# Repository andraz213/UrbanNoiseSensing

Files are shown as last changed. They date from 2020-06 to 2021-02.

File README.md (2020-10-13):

# Sensor network for urban noise sensing with IoT
Bachelors thesis

Currently on: http://urbannoisesensing.biolab.si/

## Overview

Noise is a huge health and quality of life hazard. It is most prominent in big cities, especially in city centers. 
There are ways to manage the amount and type of noise being present in these environments.
Material and architectural choices can have a tremendous impact on noise. 
But good decisions can only be made with an appropriate amount of information. A lot of times, there's not enough data to show that something needs to be done, let alone what kind of impact a specific choice will have on overall noise.

This system will help city planners and architects discover where most changes are needed and what kind of impact their past choices have on overall noise levels. 
There are a lot of systems that measure noise on a macro level. There are sensors placed on each street and research is done on a city level. 
This system will take a different approach. There will be multiple sensors on each street, meaning that research will be done on a micro-level. We want to figure out how very specific materials and structures impact noise levels in the real world. That is possible by deploying a lot of affordable sensors and using the latest machine learning methods that take into account spatial and temporal dimensions. 

This is a highly specialized system with tightly defined goals and specifications.
Here are most of these goals:

- affordable sensor nodes
- synchronized data sampling 
- FFT spectral analysis and noise volume data
- battery-powered and autonomous operation for at least a few days at a time
- wireless 
- REST API interface for data collection and querying
- support for geospatial data
- backend deployment on a local server
- easy and intuitive sensor deployment

## Basic structure

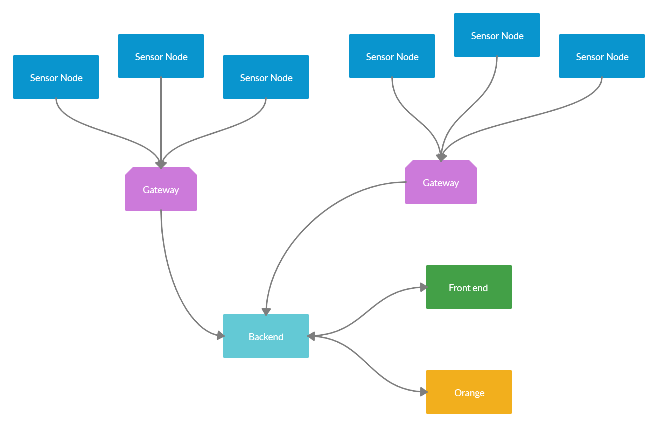
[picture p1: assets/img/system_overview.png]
System Overview


The heart of this system is a backend that is deployed on a local server. It is using Node.js, Express, and MongoDB to expose the appropriate endpoints, do basic data processing and data storage.

Gateways are needed to overlay the data from sensors to the backend. Direct wifi connection is way too inefficient for this application, that's why a special low power, low overhead wireless protocol will be used to transfer captured data from the sensors to the gateway and the to the backend. 

Sensors will consist of a low powered MCU that supports wifi-like protocols used in this system and offer enough processing power to do the FFT spectral analysis as close to the source of data to cut down on bandwidth power cost, a low-cost microphone with a flat frequency response curve and tight manufacturer tolerances, a battery to power the sensor node and some other miscellaneous components. 

The front end will enable administrators to check sensor staus and create sensor deployments. Deployments are a way of provisioning sensors on a project. 

The end-users and researchers will be able to access the data through REST API endpoints and use it in Orange or other machine learning or research tool. 

# System usage

The general concept is to create deployments. Since batteries in the sensors will only last a few days, the act of sensing can be considered as a sort of a deployment or a study.
The system will be used to study one street or one feature at a time, so these deployments can be considered as studies of individual microelements that affect the noise. 

The general overview is then: 
1. Choose the sensors
2. Mount the sensors and get the data 
3. Access the data when doing the analysis

## First step

At first, there will be no registered sensors or gateways. The first step is to turn them all on. Gateways in their normal and only mode and sensors in their administration mode.
When all of them connect to the designated wifi hotspot, they will connect to the backend and get their unique ids, check for updates and send their telemetry data. 
The first step is the easiest and will allow for all the sensors and gateways to be programmed in the same way with the same firmware (sensors and gateways will have separate firmware).

## Create a deployment

Deployment is a way to manage data and sensors. 
It will help structure and navigate the data and it will make the sensor management a lot easier. 

Here are the steps to creating a deployment:
1. Set the deployment name and description
2. Select sensors that will be used in this deployment
3. Place the sensors on a map to set their location
4. Select which gateways will be used 
5. Place gateways on the map and type in wifi credentials
6. Save changes

When the changes are saved, the new deployment and appropriate new data buckets will be created. Deployments will allow a quick overview of the latest data and sensor status after sensors are deployed on location.

## Before sensing

All of the sensors must be turned on in the administration mode to collect all the necessary setup data. 
After the data has been transferred, the sensors can be turned off until they're mounted in their spots. 

## Afer sensing

After the sensing is over, the deployment can be marked as finished. All the sensors and gateways will be released and their location and current deployment will be set to null to indicate that they are ready to be deployed again. 

The data is available while the deployment is active and after the sensing is over.

# Sensor node

## Firmware

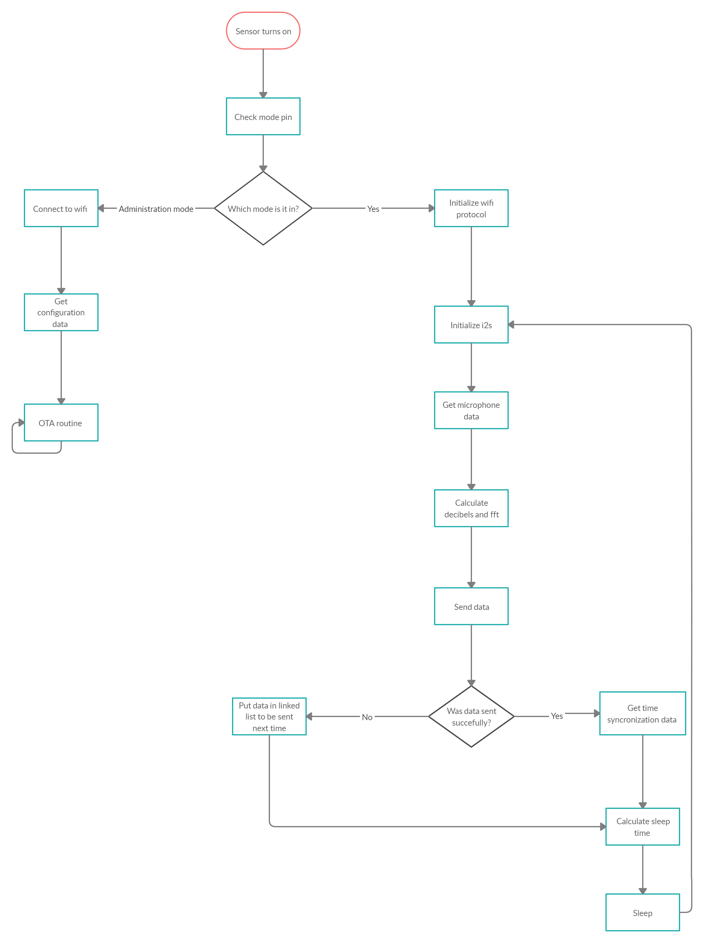
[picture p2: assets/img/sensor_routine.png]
Sensor routine


A general overview of how the firmware on the sensor node will operate.

### Setting up

When the sensor node is first programmed, it should have generic settings.
The only thing set is what wifi it should connect to.
What's next?

Firstly, it needs a unique classifier or id, so the server knows which node sent the data. Luckily, every esp comes with a unique mac address. It will be used to acquire a unique identifier from the backend. 

Then it needs to send telemetry data like firmware version, battery voltage, mac address,...

It should go something like this:

1. Connect to wifi
2. Send a "do you know me" message to the server with mac address
3. Wait for a response
4. If ok, send telemetry data

### Provisioning

Once the sensor node is set up, it needs to get some more information before it can start measuring and sending the data.

It needs:

- Gateway mac address. To send data with ESPNOW protocol, the device needs to know the MAC address of the receiver
- Sampling rate. While one measurement per second might be fine, it needs to be modifiable to make it more robust
- Frequency range. While most noise we're interested in is below 1kHz, this needs to be modifiable as well

Most provisioning work is done on the backend, so this is probably all that is needed here.

This provisioning data is sent when the sensor node is turned on in the administration mode and connected to the wifi.

### Sensing

The other mode of operation is sensing.
Before it can start collecting the data and sending it to the gateways, it needs setup data. This data is sent after the deployment is created in the frontend and the sensor node has been turned on in the administration mode.

Sensing mode is a continuous cycle of four activities:
1. Getting the readings
2. Processing the data 
3. Sending the data 
4. Sleeping

Another activity is time synchronization. The sensor asks gateway what time in milliseconds it is, so it can put a time stamp on the sensed data when sending it and to start collecting sound samples at the same time as all the other sensors. 

#### Getting the readings

The sensor of choice here is a MEMS microphone (INMP441). It communicates through the i2s protocol. This protocol is a specialized protocol for transferring sound data.
Before actually getting the data, the i2s driver needs to be initialized. 
Once the driver has been initialized, the DMA transfers data from the i2s peripheral device to the designated buffer. 
After the buffer is full, it needs to be read. 

The whole operation should go like this:
1. Initialize 12s driver
2. Wait 100ms
3. Read the data from the buffer

#### Processing the data 

Once the data has been collected from the i2s buffer, it needs to get processed. 
Three main processing tasks need to be done in this stage. 

1. Calculate the fft
2. Calculate the decibels
3. Lower the FFT resolution to 10-20 frequency ranges

#### Sending the data 

After the data has been processed, it needs to be sent. 

the data will be packaged into a struct and sent.

```
struct data_transfer_struct
{    
    float decibels;
    long time;
    int fft_spectrum [10-20];
};

``` 

When the data is sent, an automatic acknowledgment is done. If the data was successfully sent, the outgoing packet is discarded and the device can sleep.
If data transmission failed, the data must be saved and sent at a later time. It will be done in this stage when the next data transfer is successful.  

#### Sleeping

After sending is done, the MCU needs to go to sleep to conserve power and extend battery life. 
ESP32 supports different types of sleep:
- modem sleep
- light sleep
- deep sleep
- hibernation

Each has its advantages. I chose light sleep for this application. It does have much higher consumption than deep sleep, but it wakes up faster. 
Waking up from deep sleep takes about 250ms. That is a significant portion of the sensing mode operating cycle. 
Light sleep retains all the data in ram and execution can be resumed right after the light sleep function call. 

## Hardware

### MCU

I chose ESP32 MCU for this project.
It has excellent library support, wifi range is quite large, it has i2s for the microphone, it has great low power capabilities, it is powerful enough for all fft calculations, price.

The exact specific model is WROOM 32U because it has an external antenna connector. PCB antennas tend to be spotty and have a lot of signal shape peculiarities that are less than ideal in this kind of application.
The bad thing about this is that all of the development boards have a very inefficient LDO AMS1117. It is a voltage regulator with a high quiescent current. It consumes 5mA of power at all times. That is unacceptable. I will have to replace those with a more efficient model like MCP1825S. It has a quiescent current of only 220uA, which is far from the lowest, but it's good enough for this application.

### Antenna

This is yet to be determined. I have a few antennas ordered off of aliexpress, but I have to test them first. A lot of antennas are poorly made or just plain wrong.

### Battery

Sensors will be powered by one or two 18650 batteries. They seem to be a good choice because of their low price and availability. I'm not sure whether ordering them off aliexpress is a good idea tho.
Battery management will be done with a cheap tp4056 board. It has a charging circuit, overcharge protection, overcurrent protection, and over-discharge protection built into a small footprint.
I will use battery holders since I'm not comfortable with welding wires directly to the batteries.

### Microphone

A MEMS i2s microphone was chosen. MEMS microphones generally have very tight manufacturing tolerances and a flat frequency response curve. They are weather-resistant and can work under extreme temperature conditions.

INMP441 was chosen for an affordable price, great performance, compatibility with esp32, and because it comes on an easy to use a breakout board.

Decibel meter project: https://github.com/ikostoski/esp32-i2s-slm

I still have to source an appropriate wind protector.

### Enclosure

It will most probably be a weatherproof ABS plastic container. 
Haven't found one yet.

# Gateway

Gateway will be used to receive data from the sensors and send it to the backend. 
If I was only using ESPNOW protocol, I could only use one ESP32 in the gateway, but because I'm also using 802.11LR protocol, I will need two of them. 
The first one will handle all the data coming from the sensors and the time synchronization. The second one will take the received data, package it into JSON format, and send it to the backend.

These two ESP32s will communicate over the UART connection with a special PJON protocol. https://www.pjon.org/ThroughSerial.php

# Backend

## Database 

MongoDB will be used.
Measurements will be collected in size based buckets. 

### Size based buckets

MongoDB is not equipped to handle time-series data very well. Many other databases would be much more appropriate from a performance standpoint.
This can be mitigated with a few clever tricks. 

The main one is to store data in size based buckets. A naive approach to storing data is to just save each measurement as a single document. This is easier to implement, but the problem arises when the number of sensor nodes increases. If data collection is done every second and there are 20 nodes, it would mean that there would be more than 1.7 million new documents created every single day. Querry performance even after one month would be less than ideal. 
That's why I will use buckets to store data. Most of the data stored in a single document is be the same as a lot of other documents, so they can be merged. Sensor node does not move, its id does not change and the deployment id doesn't change as well, so I need to store all that data once and then just append measurement data to an array. Each element of that array will have the measurement data and a timestamp. If bucket size is set to 1000, there will be only about 1700 new documents created every day, or about 87 per single sensor.   

## Data structure 

MongoDB is a document-driven database. 

Models used:

- Deployment 
- Data
- Gateway
- Sensor 

### Deployment

This model will be used to store all the relevant deployment-related data and configuration.

```
id: number
name: string
description: string
sensors: [sensor.id, coordinates]
gateways: [gateway.id, coordinates]
start: time
finish: time
measurement_num: number
tags: [string]
```
 
- id is a random unique number generated by MongoDB used as an identifier.
- name is a string that is used to recognize deployments easier.
- description is a deployment description with more details about this deployment. 
- sensors is an array that will save which sensors are deployed where.
- gateways is an array of gateway ids and location data
- start is the time of the first measurement
- finish is the time of the last measurement
- measurement_num is the number of measurements
- tags is an array of tags that will help to search 

### Sensor

This model will hold crucial sensor data. 

```
id: number
name: string
mac: [number] (maybe string)
deployments: [deployment.id]
current_deployment: deployment.id
current_location: [number]
last_telemetry: time
last_data: data.id
firmware_version: string
battery_voltage: number
```

- id will hold the unique identifier
- name is a randomly generated name that will make identification easier to humans
- mas is a mac address of this sensor
- deployments is an array of all past deployments
- current_deployment is the id of the current deployment
- current_location is the current location of the sensor
- last_telemitry is the time and date of the last received telemetry
- last_data is the id of the last data bucket that is currently getting filled up
- firmware_version is the version of currently installed firmware
- battery_voltage is last measured voltage

### Gateway

Will hold all the relevant data for the gateway.

```
id: number
name: string
mac: [number] (maybe string)
deployments: [deployment.id]
current_deployment: deployment.id
wifi_credentials: [string]
current_location: [number]
last_telemetry: time
firmware_version: string
```

- id will hold the unique identifier
- name is a randomly generated name that will make identification easier to humans
- mas is a mac address of this sensor
- deployments is an array of all past deployments
- current_deployment is the id of the current deployment
- wifi_credentials is to let the gateway know which wifi it should connect to when it is deployed 
- current_location is the current location of the sensor
- last_telemitry is the time and date of the last received telemetry
- firmware_version is the version of currently installed firmware

### Data

Is a bucket structure that will hold incoming data.

```
id: number
sensor: sensor.id
deployment: deployment.id
location: [number]
size: number
first: time
last: time
data: [data structure]
```

- id is a unique identifier
- sensor is which sensor is this data from
- deployment is which deployment does this data belong to
- location is where was this location captured
- size is the number of measurements data currently in this bucket
- first is the time of the first measurement in this bucket
- last is the time of the last measurement in this bucket 
- data is an array of measurements, each measurement will have its timestamp and the data 

I might implement this as a linked list. Just to make it easier to get the data in the right order. I'm not sure whether this is a good idea yet, but it might be useful. 

## Exposed data 

Data about measurements, sensors, and gateways will be available through REST API for analysis in Orange or other platforms.

I don't know what exact data will be needed, but here are my guesses.

### GET /api/deployment

It will return an array of basic deployment data from all deployments.

```
[
id: number
name: string
number_of_sensors: number
start: time
finish: time
number_of_measurements: number
]
```

### GET /api/deployment/{deployment.id}

It will return a single document with the same data as the deployment model.

```
id: number
name: string
description: string
sensors: [sensor.id, coordinates]
gateways: [gateway.id, coordinates]
start: time
finish: time
measurement_num: number
tags: [string]
```

### GET /api/sensor

It will return an array of all sensors with basic data.

```
[
id: number
name: string
current_deployment: deployment.id
battery_voltage: number
]
```

### GET /api/sensor/{sensor.id}

It will return all data that is in the sensor model 

```
id: number
name: string
mac: [number] (maybe string)
deployments: [deployment.id]
current_deployment: deployment.id
current_location: [number]
last_telemetry: time
last_data: data.id
firmware_version: string
battery_voltage: number
```

### GET /api/gateway

It will return an array of all gateways with basic data.

```
[
id: number
name: string
current_deployment: deployment.id
]
```

### GET /api/gateway/{gateway.id}

It will return all data that is in the gateway model 

```
id: number
name: string
mac: [number] (maybe string)
deployments: [deployment.id]
current_deployment: deployment.id
current_location: [number]
last_telemetry: time
firmware_version: string
```

### Data 

Querying data will be the major part of backend work. 

It's more or less a guessing game at this point, but here are my predictions as to which endpoints will be needed.

#### GET /api/data/deployment/{deployment.id}

It will return all the data from a single deployment. 

```
[
sensor: sensor.id
deployment: deployment.id
location: [number]
size: number
first: time
last: time
data: [data structure]
]

```

The structure will be similar to the one seen in the data model, but all the data from a single sensor will be in a single array.

#### GET /api/data/deployment/{deployment.id}/{last_n}

It will return the last n measurements.
Note that one measurement is actually one measurement per sensor, so this method will return last n measurements for each sensor.

```
[
sensor: sensor.id
deployment: deployment.id
location: [number]
size: number
first: time
last: time
data: [data structure]
]

```

#### POST /api/data/deployment/{deployment.id}/

The request body will contain additional query data. 

Possible additional parameters:
- return measurements before this time
- return measurements after this time
- return measurements from these sensors 
- return last n measurements
- more?? @@@

## Exposed sensor and gateway endpoints

More REST API endpoints will be needed to set up the sensors and gateways and to make them work.

### POST /api/sensor/

This is where it all starts for the sensor. When the sensor is first turned on in administration mode, it will send its mac address to the server to register as a sensor node.
The server will return its generated id and name.
If the sensor is deployed, the server will also return basic configuration data like the nearest gateway mac address. 

### POST /api/sensor/telemitry/{sensor.id}

After the first call, the sensor will enter a loop, where it will report it's battery voltage and firmware version every few minutes. The server will return data about the latest firmware version. If there is a new firmware version, the sensor will enter the OTA mode where it waits for the update to start.
If it is already running the latest firmware, it will only report its voltage every few minutes. It is useful to have a remote battery charging status. 

### POST /api/sensor/data/

This is a gateway endpoint. It will send an array of measurements. When testing, I noticed that each POST request took almost half a second. That is way too much if the sensors are sending data every second and there are 10 sensors, it would take 5 seconds to send data each second. So gateway will send an array of measurements that it has collected since the last time it sent data. Each measurement will have a sensor id and the actual data. The server will then insert the data into appropriate buckets.

### POST /api/gateway/

Similar to the sensor, this is where all gateways will start. The gateway will send its mac address to the server to either get its id and deployment data or register for the first time as a gateway. 
The server will respond with appropriate gateway data.

### POST /api/gateway/telemitry/{sensor.id}

An endpoint for gateways to send their telemetry data. 

# Izbira tehnologije

## Povezava senzorjev z internetom

Zahteve:
- obratovanje na baterije
- dovolj velik obseg vsaj 200m obseg (@@@ a je to res?)
- hitrost prenosa podatkov, vsak senzor generira cca. 200B/s ... 20 senzorjev generira 4KB/s

### LoRa

Na prvi pogled izgleda obetavno z zelo majhno porabo energije in velikim dometom (2-3km).
Problem je izredno počasna povezava. V najboljših razmerah je 20kbps. Naše zahteve so 4KB/s * 8 = 32kbps.
LoRa po mojem mnenju potem odpade zaradi prepočasnega prenosa podatov

### NRF24l01+

Je dokaj preprosta tehnologija, ki omogoča hitro povezavo na srednje dolge razdalje, je dovolj hitro, ampak ima dve pomankljivsoti.
Tehnologija dovoljuje največ 6 povezav na vsak modul. Za potrebe naše uprabe bi načeloma lahko uporabili mrežo takih točk, ampak to poveča kompleksnost projekta in oteži postavljanje senzorjev

### 802.11LR

Espressif, proizvajalec čipa ESP32 je implementiral poseben protokol, ki je kkompatibilen z 802.11, ampak ga navadne wifi točke ne zaznajo. Omogočal naj bi daljši domet kot navaden wifi.
To je doseženo z zmanjševanjem hitrosti pod 1Mbps, kar bi bilo za ta projekt še zmeraj dovolj. Problem tega je, da je še zmeraj prisoten overhead od wifija, kar močno poveča količino porabljene energije. Tu bi moral podatke pošiljati recimo enkrat na minuto, kar ne bi bilo več real time, ampak zaradi porabe energije ne bi šlo drugače. Tu bi tudi potreboval gateway, ki bi sporočila preko tea protokola sprejela in potem poslala na internet.

### Kreativne alternative

#### SD kartice

V modulu je RTC, ki se ga enkrat nastavi in potem zansljivo drži pravilen čas in podatki se beležijo na SD kartico, s katere se podatki poberejo ob polnenju baterij.

#### GSM moduli

Naprava komunicira preko GSM vmesnika in tako pošilja podatke na strežnik. Tu je še dodatni strošek recimo 7€ na mesec na senzor. Plus GSM modul, ki stane 5€. Ne vem kako je s porabo energije, ampak če bi podatke pošiljal pv paketih, bi lahko to minimiziral.

### Testiranje tehnologij

Ker imam doma nekaj nrf24l01+ modulov z vgrajenim ojačevalnikom moči, sem testiral domet in zanesljivost.
Prav ta ko imam doma nekaj ESP32 modulov s katerimi sem testiral domet 802.11LR protokola.

Zaenkrat se je 802.11LR izkazal za boljšega. Domet je vsaj še enkrat daljši.

Oba modula sem imel na okenjski polici svoje sobe. Hodil sem po kraju in opazoval koliko sporočil je prišlo do sprejemnika.

nrf24 z vgrajenim ojačevalnikom signala in cca 3dBi anteno:
- Takoj ko je bila med mano in oddajnikom hiša, je sperjemnik izgubil signal
- Line of sight doseg je bil približno 80m

802.11LR ESP32 z vgrajeno anteno na tiskanem vezju s cca 2dBi:
- Je deloval tudi na drugem koncu hiše in do neke mere celo ko je bila med mano in oddajnikom sosedova hiša
- Line of sight doseg je bil približno 160m

Test sem z 802.11LR ponovil doma v hiši. Oddajnik sem postavil na podstrešju na skrajno vzhodni strani.
- V istem nadstropju je signal brezhiben
- Eno nadstropje nižje je signal brezhiben in se sprejemnik poveže v vseh delih nadstropja razen v najbolj zahodnih delih hiše.
- V spodnjem nadstropju se sprejemnik poveže in brezhibno sprejema signal povsod razen v 1/3 najbolj zahodnega dela hiše

Ob ponovitvi testa 802.11LR z oddajnikom na podstrešju, sem izmeril line of sight domet 200m, ampak le če je bil modul obrnjen v pravo smer. Zunanja antena bi pri tem precej pomagala.

Testirano je bilo na razvojnih ploščah, ki imajo na tiskanem vezju vgrajene antene. Te antene najverjetneje niso najboljše, kar poemni, da bi z boljšimi antenami dosegli še boljše rezultate.

### Trenutnne možnosti

#### LoRa

Zaenkkrat odpade, razen če zmanjšamo količino poslanih podatkov pod 15kbps.

#### NRF24

Pogojno bi se dalo, če bi strateškko postavili senzorje in zbirnike podatkov.

#### 802.11LR

Zaenkrat se mi zdi to najboljša opcija.

Za:
- Daljši domet od nrf24 brez dodatnih optimizacij
- Cenejši od LoRa (7€ za MCU in oddajanje vs. 15€ za MCU in LoRa)
- Cenejša in bolj preprosta centralna postaja kot LoRa (dva ESP32 modula, eden je povezan na iinternet, eden pa zbira podatke iz senzorjev in jih preko I2C ali SPI vmesnika pošilja drugemu)

Proti:
- Večja poraba energije (to bi reševal s paketnim pošiljanjem podatkov)
- Najbolje deluje, ko je med oddajnikom in sprejemnikom line of sight (to bi reševal z večjim številom centralnih postaj, ki so tu cenejše in manjše od LoRa in manj odvisne od postavitve kot nrf24)

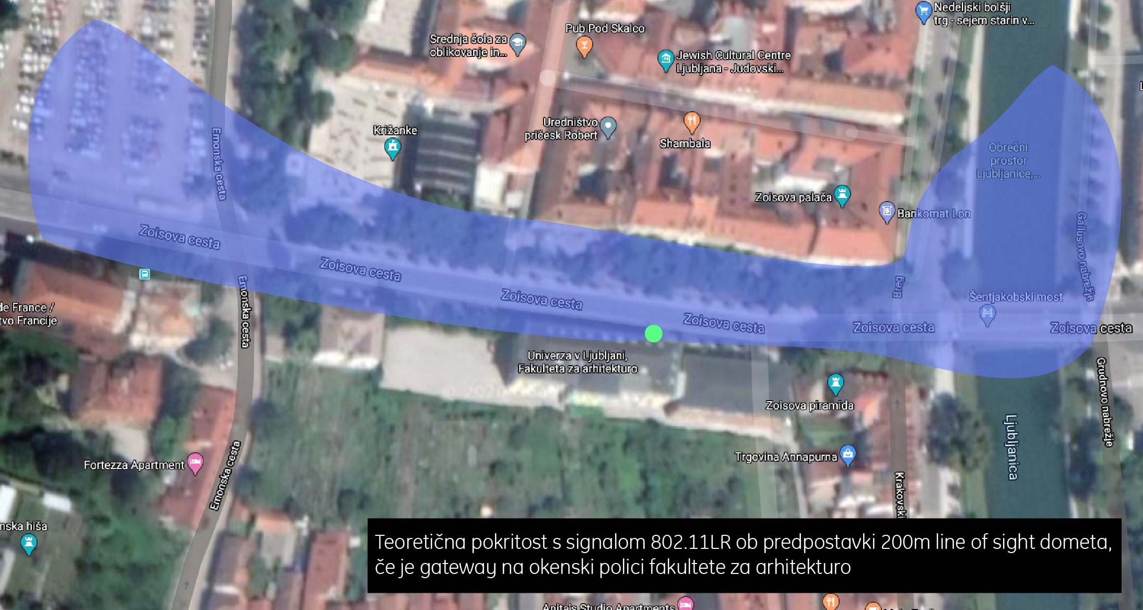
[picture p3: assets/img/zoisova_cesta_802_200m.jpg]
Domet na Zoisovi cesti


# Zapisek s sestanka

Strojna in programska infrastruktura za sledenje in analizo hrupa v urbanih okoljih
Cilj: sistem med seboj vsaj deset časovno sinhronizirinah senzorjev, ki jih postavimo na različne lokacije v nekem lokalnem okolju. Meritve gredo v oblak, najbrž preko centralne naprave, ki naprej meritve shrani lokalno. Dva načina dela: po deset meritev na sekundo (spremljamo lahko vpliv mimoidočega avtobusa) ali ena meritev na minuto. Iz oblaka meritve preberemo v Orange, spremljamo časovni potek za dano okno in v geo karti spreminjanje hrupa v času.
- poiskati ustrezni senzor
- casing
- fft
- kombinacija z ESP32 ali podobnim, avtonomna enota
- poiskati tudi referenčni merilec in narediti sistem za umerjanje instrumenta (tudi vir zvoka), morda lahko pomaga kdo iz FE
- seznam opreme za nakup (čimprej)
- sestaviti merilno enoto, ki je avtonomna (baterija) in se poveže na centralno vozlišče
- sestaviti centralno vozlišče
- testiranje na FRI
- sistem za umerjanje

- kateri problem rešujemo
- zasnova arhitekture
- seznam stvari za nakup
- ali lahko začnete s prototipom: senzor, komunikacija, iot platforma ali baza, branje v orange-u (python)

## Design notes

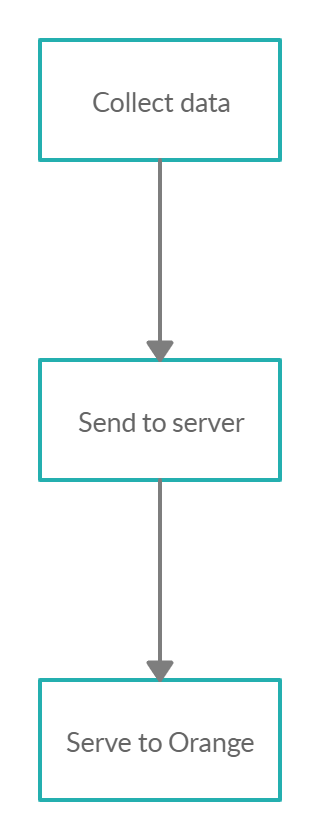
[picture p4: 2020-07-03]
assets/img/simplest_overview.png

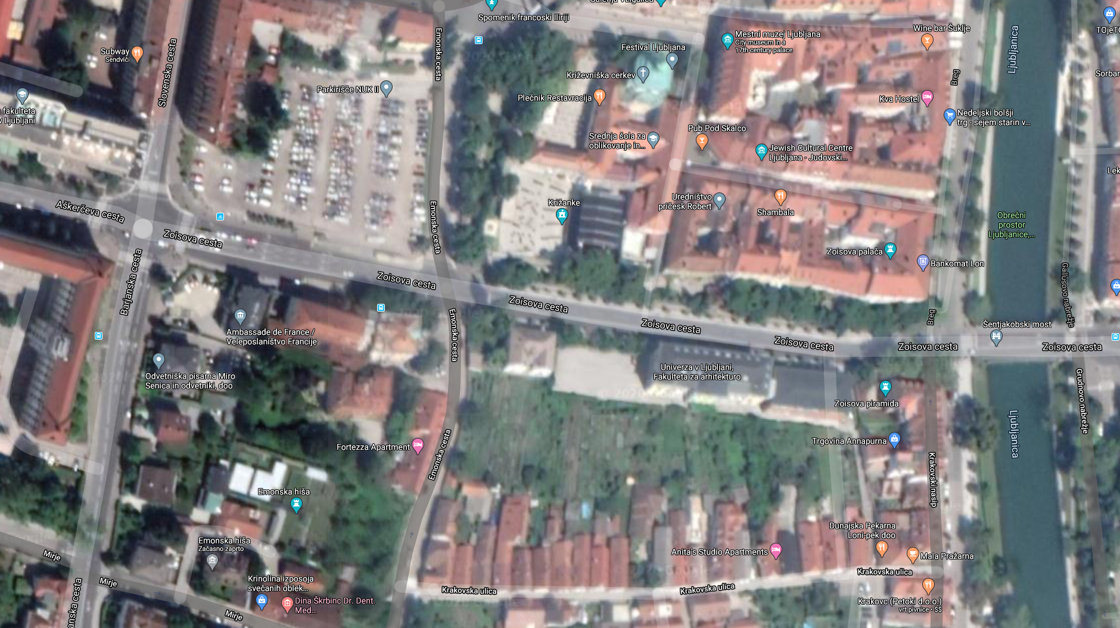
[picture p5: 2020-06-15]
assets/img/zoisova_cesta.png

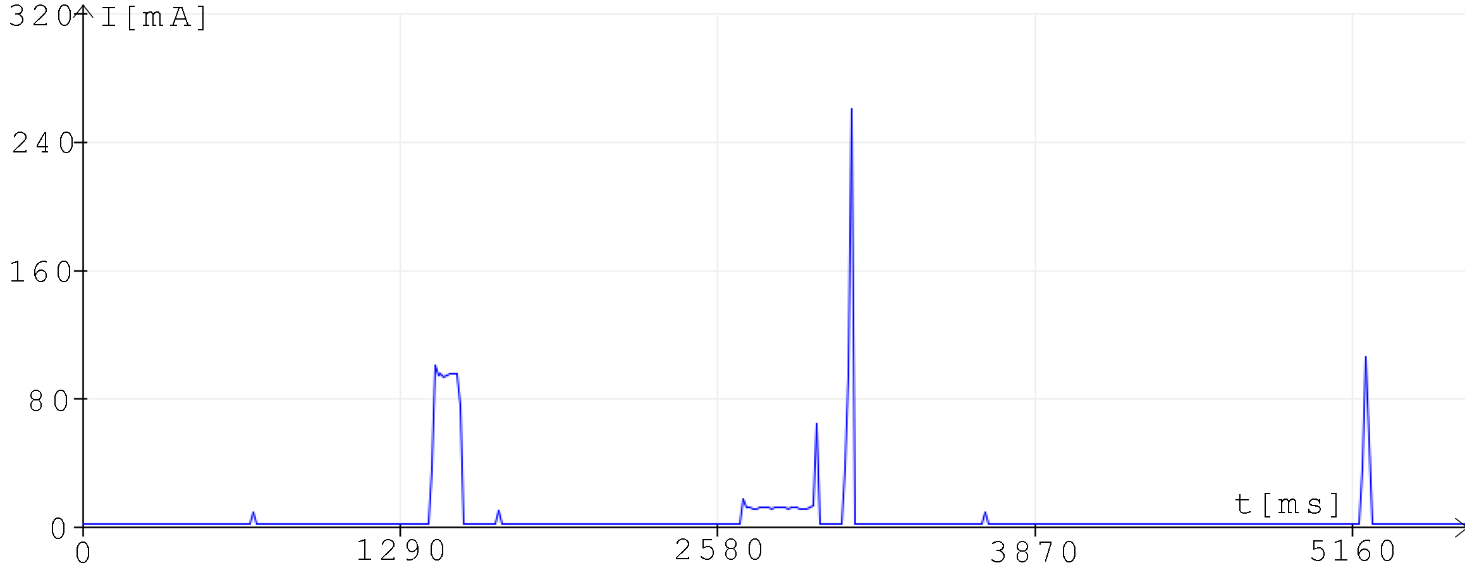
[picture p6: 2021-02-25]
Diplomska naloga/slike/4 s blabla poraba.png

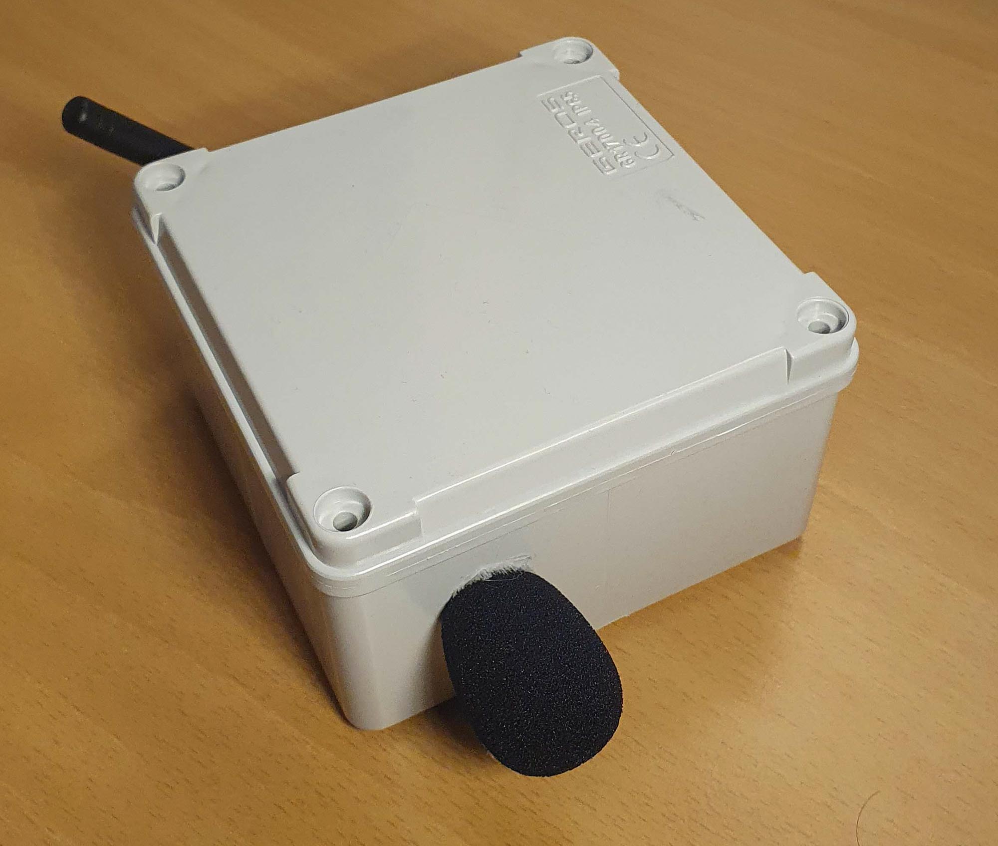
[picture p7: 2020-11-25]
Diplomska naloga/fotografije/sestavljena_merilna2.jpg

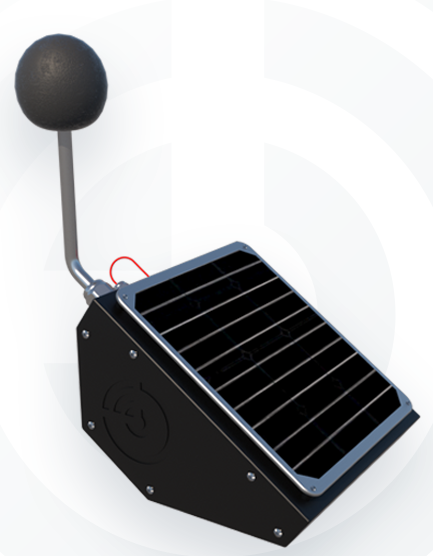
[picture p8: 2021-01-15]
Diplomska naloga/slike/iotsoundsensor_enota.png

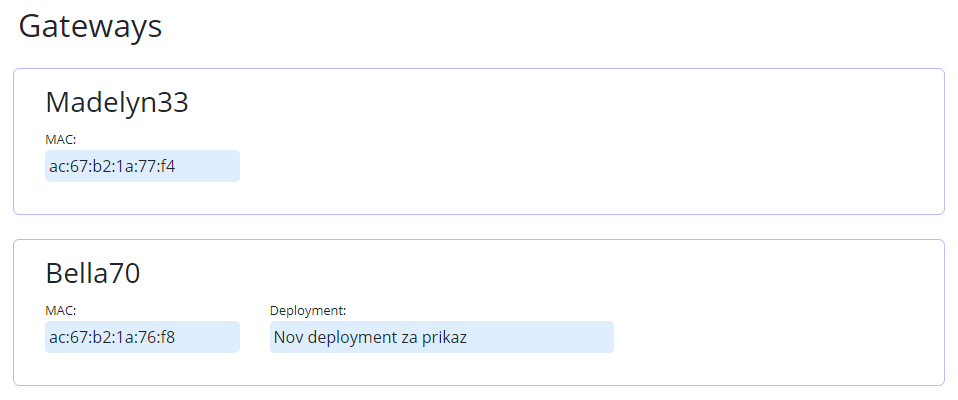
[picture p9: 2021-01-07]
Diplomska naloga/slike/uv-zbirne-enote.png

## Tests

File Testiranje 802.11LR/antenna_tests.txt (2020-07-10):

3dbi antena
10:03:21.851 -> 1: PSP256 (-63)*
10:03:21.851 -> 2: AMIS-18C595 (-82)*
10:03:21.851 -> 3: vanc (-82)*
10:03:21.884 -> 4: Jereb (-84)*
10:03:21.884 -> 5: Wifi (-85)*
10:03:21.884 -> 6: TP-Link_98E6 (-92)*
10:03:21.884 -> 7: TelekomSlovenije_856b (-92)*
10:03:21.919 -> 8: panj1 (-92)*

nrf24 antenna
10:08:47.949 -> 1: PSP256 (-62)*
10:08:47.984 -> 2: AMIS-18C595 (-79)*
10:08:47.984 -> 3: vanc (-82)*
10:08:47.984 -> 4: TelekomSlovenije_856b (-88)*
10:08:48.019 -> 5: TP-Link_98E6 (-90)*
10:08:48.019 -> 6: Jereb (-91)*
10:08:48.019 -> 7: panj1 (-91)*
10:08:48.019 -> 8: Telemach-6b5d (-92)*
10:08:48.054 -> 9: Wifi (-93)*
10:08:48.054 -> 10: HP-Print-0D-Officejet Pro 8620 (-93) 

pcb antena (best case z vrtenjem okol po parih poskusih)
10:11:21.816 -> 1: PSP256 (-68)*
10:11:21.816 -> 2: AMIS-18C595 (-87)*
10:11:21.816 -> 3: vanc (-87)*
10:11:21.816 -> 4: TP-Link_98E6 (-94)*

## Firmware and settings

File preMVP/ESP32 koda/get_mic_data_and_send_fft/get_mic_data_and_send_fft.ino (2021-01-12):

#include <driver/i2s.h>
#include "arduinoFFT.h"
#include <ArduinoJson.h>
#include <WiFi.h>
#include <HTTPClient.h>
#include "esp_wifi.h"

const char* ssid = "";
const char* password = "";

//Your Domain name with URL path or IP address with path
const char* serverName = "http://noise-sensing-pre-mvp.herokuapp.com/api/measurements";


arduinoFFT FFT = arduinoFFT(); /* Create FFT object */
const i2s_port_t I2S_PORT = I2S_NUM_0;

const int SAMPLING_FREQUENCY = 3000;
const int BLOCK_SIZE = 256;
int32_t samples[BLOCK_SIZE];
double vReal[BLOCK_SIZE];
double vImag[BLOCK_SIZE];
long previous = 0;

void setup() {
  Serial.begin(115200);
  Serial.println("Configuring I2S...");
  init_i2s();
  connectWifi();
  // Configuring the I2S driver and pins.
  // This function must be called before any I2S driver read/write operations.

}

void loop() {

  if (millis() - previous > 1000) {
    previous = millis(); 
    long start = micros();
    getSamples();
    Serial.println("Getting samples lasted: ");
    Serial.println(micros()- start);

    start = micros();
    analyzeData();
    Serial.println("Analyzing data lasted: ");
    Serial.println(micros()- start);

    start = micros();
    String dataToSend = createJSON();
    Serial.println("Creating JSON lasted: ");
    Serial.println(micros()- start);

    
    start = micros();
    connectWifi();
    Serial.println("Connecting to WiFi lasted: ");
    Serial.println(micros()- start);
    

    start = micros();
    sendDataToServer(dataToSend);
    Serial.println("Sending data lasted: ");
    Serial.println(micros()- start);
    Serial.println();
    Serial.println();
  }
  delay(10);
}


void connectWifi() {

  if (WiFi.status() != WL_CONNECTED) {
    WiFi.begin(ssid, password);
    Serial.println("Connecting");
    while (WiFi.status() != WL_CONNECTED) {
      delay(500);
      Serial.print(".");
    }
    //esp_wifi_set_ps(WIFI_PS_MAX_MODEM);
  }


}

void init_i2s() {
  esp_err_t err;

  // The I2S config as per the example
  const i2s_config_t i2s_config = {
    .mode = i2s_mode_t(I2S_MODE_MASTER | I2S_MODE_RX), // Receive, not transfer
    .sample_rate = SAMPLING_FREQUENCY,                 // 16KHz
    .bits_per_sample = I2S_BITS_PER_SAMPLE_32BIT, // could only get it to work with 32bits
    .channel_format = I2S_CHANNEL_FMT_ONLY_RIGHT, // although the SEL config should be left, it seems to transmit on right
    .communication_format = i2s_comm_format_t(I2S_COMM_FORMAT_I2S | I2S_COMM_FORMAT_I2S_MSB),
    .intr_alloc_flags = ESP_INTR_FLAG_LEVEL1,     // Interrupt level 1
    .dma_buf_count = 4,                           // number of buffers
    .dma_buf_len = BLOCK_SIZE                     // samples per buffer
  };

  // The pin config as per the setup
  const i2s_pin_config_t pin_config = {
    .bck_io_num = 14,   // BCKL
    .ws_io_num = 15,    // LRCL
    .data_out_num = -1, // not used (only for speakers)
    .data_in_num = 32   // DOUT
  };


  err = i2s_driver_install(I2S_PORT, &i2s_config, 0, NULL);
  if (err != ESP_OK) {
    Serial.printf("Failed installing driver: %d\n", err);
    while (true);
  }
  err = i2s_set_pin(I2S_PORT, &pin_config);
  if (err != ESP_OK) {
    Serial.printf("Failed setting pin: %d\n", err);
    while (true);
  }
  Serial.println("I2S driver installed.");

}


void getSamples() {




  for (int i = 0; i < BLOCK_SIZE; i++) {
    samples[i] = 0;
  }
  delay(120);
  int num_bytes_read = i2s_read_bytes(I2S_PORT,
                                      (char *)samples,
                                      BLOCK_SIZE * 4,     // the doc says bytes, but its elements.
                                      portMAX_DELAY); // no timeout
  delay(120);
  num_bytes_read = i2s_read_bytes(I2S_PORT,
                                  (char *)samples,
                                  BLOCK_SIZE * 4,     // the doc says bytes, but its elements.
                                  portMAX_DELAY); // no timeout

  int samples_read = num_bytes_read;
  //Serial.println(samples_read);

  if (samples_read > 0) {

    float mean = 0;
    for (int i = 0; i < BLOCK_SIZE; ++i) {
      mean += abs(samples[i] / (float)BLOCK_SIZE);
      //Serial.println(samples[i]);
    }
    //Serial.println(mean);
  }



  //i2s_driver_uninstall(I2S_NUM_0);


}



void analyzeData() {
  for (int i = 0; i < BLOCK_SIZE; i++) {
    vReal[i] = (double)samples[i];
    vImag[i] = 0;
  }

  FFT.Windowing(vReal, BLOCK_SIZE, FFT_WIN_TYP_HAMMING, FFT_FORWARD);  /* Weigh data */

  FFT.Compute(vReal, vImag, BLOCK_SIZE, FFT_FORWARD); /* Compute FFT */

  FFT.ComplexToMagnitude(vReal, vImag, BLOCK_SIZE); /* Compute magnitudes */

  double x = FFT.MajorPeak(vReal, BLOCK_SIZE, SAMPLING_FREQUENCY);
  Serial.println(x, 6);

}


String createJSON() {
  StaticJsonDocument<2000> doc;
  doc["sensor"] = "prvi testni senzor";
  JsonArray location = doc.createNestedArray("location");

  location.add(46.181334);
  location.add(14.494998);


  JsonArray fftValues = doc.createNestedArray("fftValues");
  //JsonArray fftFrequencies = doc.createNestedArray("fftFrequencies");

  for (int i = 0; i < BLOCK_SIZE / 20; i++) {
    double val = 0;
    double freq = 0;

    for (int j = 0; j < 10; j++) {
      val += vReal[i * 10 + j] / 10.0;
      freq += (i * 10 + j);
    }
    fftValues.add(log(val));
    //fftFrequencies.add(freq * SAMPLING_FREQUENCY / 10000);


  }

  int decibels = 0;
  for (int i = 0; i < BLOCK_SIZE; i++) {
    decibels += (int)(abs(samples[i]) / BLOCK_SIZE);
  }
  doc["decibels"] = decibels;
  String jsn;
  serializeJson(doc, jsn);
  //Serial.println(jsn);

  return jsn;
  //serializeJsonPretty(doc, Serial);



}






void sendDataToServer(String jsnData) {
  HTTPClient http;
  http.begin(serverName);

  // Specify content-type header
  http.addHeader("Content-Type", "application/json");
  // Data to send with HTTP POST
  String httpRequestData = jsnData;
  // Send HTTP POST request
  int httpResponseCode = http.POST(httpRequestData);

  Serial.print("HTTP Response code: ");
  Serial.println(httpResponseCode);

  // Free resources
  http.end();


}

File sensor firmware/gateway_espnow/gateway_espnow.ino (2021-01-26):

#include "handle_esp_now.h"
#include "handle_serial.h"


void setup() {

  pinMode(33, INPUT);
  // put your setup code here, to run once:

  Serial.begin(115200);
  Serial2.begin(921600);
  Serial2.setRxBufferSize(1024);

  setCpuFrequencyMhz(240);

  init_wifi();

  // init two tasks



  // task one
  xTaskCreatePinnedToCore(
    TaskEspNow
    ,  "TaskEspNow"
    ,  32000  // Stack size
    ,  NULL
    ,  1  // Priority
    ,  NULL
    ,  0);


  // task two
  xTaskCreatePinnedToCore(
    TaskSerial
    ,  "TaskSerial"
    ,  32000  // Stack size
    ,  NULL
    ,  1  // Priority
    ,  NULL
    ,  1);




}

void loop() {
  // put your main code here, to run repeatedly:

}

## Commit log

2020-06-17 prva koda za ESP32 brez ozira na energijo
2020-06-18 better performance, sensor id shows up
2020-07-05 sensor node operation description
2020-07-09 random human readable name generation for sensors
2020-07-09 more sensor functions
2020-07-11 placing sensors on a map
2020-07-11 current location fix on deploying deployment
2020-07-14 made sensors and gateways look less suckish
2020-07-29 added apll clock setting and used it to maake startup time much shorter
    [get_mic_data_and_send_fft.ino, microphone.cpp]
2020-08-03 remove printlns
2020-08-07 just realized I still have to handle sensor telemetry data
2020-08-07 sensor time is synchronised with SNTP and wifi gateway is recieving telemetry and reading data
2020-08-31 print decibels
2020-09-01 sensor maintanence routine
2020-09-01 get sensor config
2020-09-02 getting battery voltage and sending telemetry, tested on all 3 boards
2020-09-03 sensor sending very much functionality
2020-09-03 still missing all the wifi sending, but otherwise works
    [gateway_wifi.ino, handle_esp_now.cpp, handle_serial.cpp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]
2020-09-11 new build with fixed gateway current_location
2020-09-23 first widget prototype
2020-10-02 moved finish button to overview tab
2020-10-08 advanced scheduling should be working now on sensors
2020-10-08 mitiwifi doesn't work (yet)
    [gateway_espnow.ino, gateway_wifi.ino, handle_json.cpp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]
2020-10-19 A lot of power efficency changes and theseis work
2020-11-04 esp32 tabela
2020-11-10 Električne sheme
    [merilna_enota.fzz, zbirna_enota.fzz]
2020-11-14 get sensor names as well fix
2020-11-15 Frontend spacing problems fix
    [gateway_wifi.ino]
2020-11-15 sensor deployment name
2020-11-19 Premik latex projekta na git
    [merilna_enota.fzz, zbirna_enota.fzz]
2021-01-18 Sensor better display
2021-01-20 les get it
2021-01-26 Updated gateways for stability
    [gateway_espnow.ino, gateway_wifi.ino, handle_esp_now.cpp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]
